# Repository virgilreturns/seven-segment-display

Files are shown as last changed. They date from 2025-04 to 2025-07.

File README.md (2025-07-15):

# seven-segment-display

# Description:
Embedded Microcontroller NUCELO-F401RE Multi-Digit Seven Segment LED Driver using Master-Transmit Only SPI communication with 74HC595 Shift Register.

The objectives of this project are to gain experience with configuring 32-bit microcontrollers, coding in C using the STMCubeIDE, learning how to use Git, using kicad to design footprints and PCBs, 
learning how to get the PCBs manufactured, and learning how to order correct components for cheap. 

This project spanned two months to complete. The code is open-source and free to use. 

# Signal Processing Flow Chart:



# Final Circuit Design



# Final PCB Design



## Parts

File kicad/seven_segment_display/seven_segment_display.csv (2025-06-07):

Reference | Qty | Value | DNP | Exclude from BOM | Exclude from Board | Footprint | Datasheet
DS1 | 1 | LTC-55623G |  |  |  | Library:LTC_5623G-SDIP
R1,R2,R3,R4,R5,R6,R7,R8 | 8 | 660 |  |  |  | Resistor_THT:R_Axial_DIN0207_L6.3mm_D2.5mm_P7.62mm_Horizontal | ~
U1 | 1 | 74AHC595 |  |  |  | Package_DIP:DIP-16_W10.16mm | https://assets.nexperia.com/documents/data-sheet/74AHC_AHCT595.pdf

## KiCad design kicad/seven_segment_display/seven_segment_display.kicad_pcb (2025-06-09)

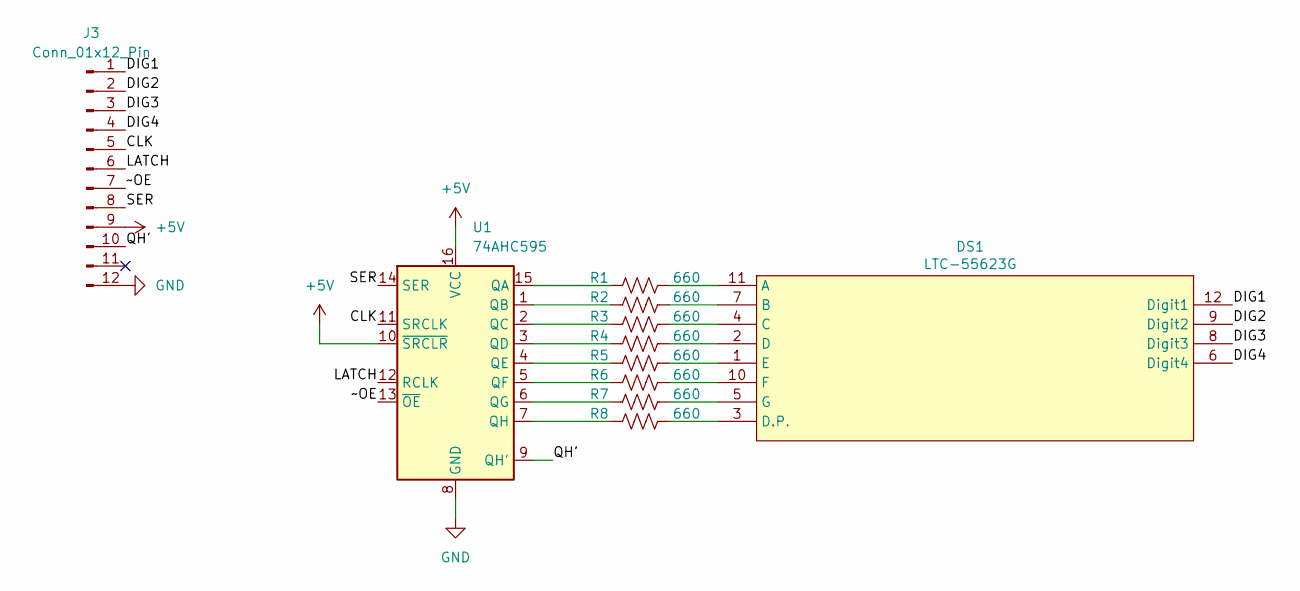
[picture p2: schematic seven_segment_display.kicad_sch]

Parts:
DS1: LTC-55623G; LTC_5623G-SDIP
J3: Conn_01x12_Pin; PinHeader_1x12_P2.54mm_Vertical
R1, R2, R3, R4, R5, R6, R7, R8: 660; R_Axial_DIN0207_L6.3mm_D2.5mm_P7.62mm_Horizontal
U1: 74AHC595; DIP-16_W7.62mm_Socket

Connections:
+5V: J3.9, U1.10 (~SRCLR), U1.16 (VCC)
/CLK: J3.5, U1.11 (SRCLK)
/DIG1: DS1.12 (Digit1), J3.1
/DIG2: DS1.9 (Digit2), J3.2
/DIG3: DS1.8 (Digit3), J3.3
/DIG4: DS1.6 (Digit4), J3.4
/LATCH: J3.6, U1.12 (RCLK)
/QH': J3.10, U1.9 (QH')
/SER: J3.8, U1.14 (SER)
/~OE: J3.7, U1.13 (~OE)
GND: J3.12, U1.8 (GND)
unnamed: DS1.11 (A), R1.2
unnamed: DS1.7 (B), R2.2
unnamed: DS1.4 (C), R3.2
unnamed: DS1.2 (D), R4.2
unnamed: DS1.3 (D.P.), R8.2
unnamed: DS1.1 (E), R5.2
unnamed: DS1.10 (F), R6.2
unnamed: DS1.5 (G), R7.2
unnamed: R1.1, U1.15 (QA)
unnamed: R2.1, U1.1 (QB)
unnamed: R3.1, U1.2 (QC)
unnamed: R4.1, U1.3 (QD)
unnamed: R5.1, U1.4 (QE)
unnamed: R6.1, U1.5 (QF)
unnamed: R7.1, U1.6 (QG)
unnamed: R8.1, U1.7 (QH)

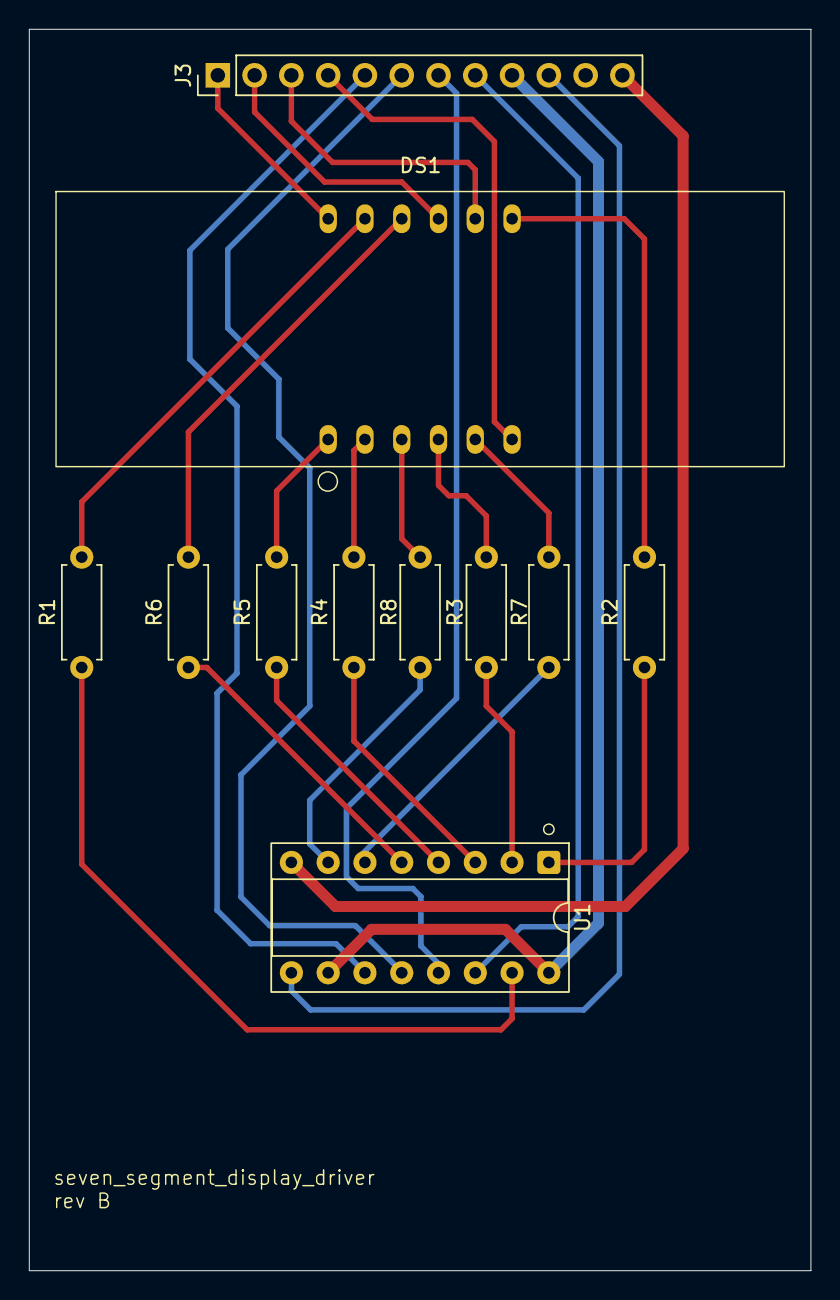
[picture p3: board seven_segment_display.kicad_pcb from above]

Board: 2 copper layers, 54.0 x 85.7 mm, 11 parts (0 on the bottom side), 27 nets.

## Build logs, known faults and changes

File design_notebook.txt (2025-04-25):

 TESTING REQ:
    -INTEGRATED TESTS: 
				     : (COMPLETED 3/20/2025) SHIFT REGISTER + 7 LEDS + BUTTON INTERFACE
					 : (COMPLETED 3/21/2025) SHIFT REGISTER + 7 SEGMENT DISPLAY, (basic test) make sure digital 0 actually is ground
					 : (COMPLETED 3/21/2025) SHIFT REGISTER + 5 DIGIT 7 SEGMENT DISPLAY 
					 : (COMPLETED 3/24/2025) SPI COMMUNICATION + LOGIC ANALYZER 
					 : (COMPLETED 3/25/2025) SPI COMMUNICATION WITH SHIFT REGISTER + 7 SEGMENT DISPLAY (1 digit, 1 character)
					 : (COMPLETED 3/26/2025) CODE ARCHITECTURE FOR MULTIPLEXING DIGITS, ACCURATE DELAYS BETWEEN TRANSMISSION
					 : (COMPLETED 4/24/2025) SPI COMMUNICATION WITH SHIFT REGISTER + 5 DIGIT 7 SEGMENT DISPLAY (use full data buf, see)
					   CHECK GPIO CONTROL PINS, DIGITAL SELECT, LATCH, TIMERS 1,2 requires debugging
					 : (COMPLETED 3/25/2025) CODE ARCHITECTURE FOR BUTTON USER INTERFACE, DEBOUNCE? EXTI CALLBACKS?
					 : (INCOMPLETE) CODE REVISION FOR BUTTON UI IN CONFORMANCE TO NEW STATE MACHINE DESIGN (config & normal)

3/17/2025
  The 74HC595 shift register will be driving up to 7 LEDs. It has a max total output of 70 mA and 35 mA for a single pin.
  With 7 LEDs, the maximum individual output pin current is 6.25 mA which can be achieved with 560 ohm resistor in series with
  the diode.

  TESTING REQ: See how much current provides a satisfactory brightness. Consider a transistor based circuit to drive more
  power for the LEDs, 

  Continue to test shift register with 3mm LEDs for now. Need to fix circuit and use 10k+ pull-up/pulldown resistors for
  SRCLOCK, RCLOCK, and SER. SRCLEAR tied to Vcc and OE tied to GND.  

  TEST REVIEW:  Extreme debounce on all pushbuttons and dip switches :(((
                Overall, shift register seems to work fine.
  
  UPCOMING TASKS:
  - Circuit design for microcontroller to shift register, start firmware for transmitting bits, 
  - Test shift register with 7 segment display, continue using 680 ohm resistors
  - (OPTIONAL) create separate 7 segment display on proto board with resistors and header pins
  - Test SPI communication with shift register and 3mm LEDs
  - Implement SPI communication with shift register and 7 segment display

3/20/2025
  - Successfully tested shift register with 7 segment display. It works as expected.
  - Need to implement SPI communication with the shift register and the 7 segment display.
 
  - further ideas for UI implementation:

 /* ------------------one button config----------------------
	One button is used to cycle through all of the seven_segment characters
	Straight forward and pin resourceful.
*/

 /* ------------------two button config / rotary encoder ----------------------
	Two buttons are used to cycle through all of the seven_segment characters
	Button 1: cycles forward
	Button 2: cycles backwards
	More intuitive than one button, but uses more pins.
*/
 /* ------------------switch encoding config----------------------
	4 dip switches are used to select a specific character to display on the seven_segment.
	Faster to select a specific character, but requires more pins, and a documentation of the encoding.
	Up to number 9 will be in binary, and the other characters can be attained via documentation.
*/

  Keep 8 diode testing setup for testing with SPI functions
  Finished basic seven segment byte transmission code.

  Interested in implementing code for the UI configs

3/21/2025

 Started soldering circuit unto protoboard, probably a bad idea because
 I just had another fantastic idea for an implementation of the project.

 2 button config, one button to cycle through characters, and the other to cycle through the digits.
 This creates a sort of text editor for the seven segment display.

 Other caveats, will need multiplexing with multiple digits, (selecting which VCC to turn on)
 While I only really want no more than 4 digits, I can use a timer to "play" the digits, and shift
 the data through the display. I.E. with 4 digits, I can display a 20 character string by shifting the characters through an array,
 then displaying the array on the 4 digits.

 I can have a timer between configuration and "play" mode, hence if there is no configuration for a certain amount of time, the display will
 start playing the string.

 The first button press of either configuration button will start the configuration mode, and then they will
 function as normal. The display will default to play mode after a certain amount of time of inactivity.

 Other features: A dip switch -> change how many digits are shifted at a time, FULL DISPLAY or BYTE-WISE shifting.
				 -> how big the string can be

 TESTING: Using Analog Discovery 3 (AD3) to read button bounce signal, familizarize with oscilloscope

 Completed:
	-refactored code to support multiple digit display
	-default data will be "Hello"
 
 3/24/2025

	Completed testing SPI communication with logic analyzer. Tested data buffers: (0xFF, 0x33, 0x88, {ASCII_TO_ENUM("HELLo") })
	
	KEY TAKEAWAYS: increase prescaler to decrease the SPI frequency to ~1 Mhz. APB1 peripheral I believe for SPI2. Sysclk / 16 ~ 1Mhz.
	Sample frequency should be at least 4 times greater than the transmission frequency.

	There is a bug where the logic analyzer can accurate detect the first buffer, but will fall out of alignment. Doesn't start reading
	immediately when the CLK goes high...

	Examining HC595 datasheet, provides timing requirements for pulse width, max CLK speeds...

	TODO: CREATE PULSE FUNCTION, ADJUST CLOCK FREQ, TRANSMISSION SEQUENCE
	      TIMING REQUIREMENTS: max CLK speed at 2.0 V = 5 Mhz, 4.5 V = 25 Mhz. Pulse Duration SRCLR 100 ns at 2V,
	      SWITCHING CHARACTERISTICS (input to output): ~250 ns

 3/25/2025
	
	Completed testing SPI communication with shift register + one digit display. 
	Tested data: (ENUM_0, - ENUM_3, ENUM_H, ENUM_n, ENUM_o)

	KEY TAKEAWAYS: ENUM_SEVSEG_CHAR list is not accurately defined, at least for some of the letters.
				 : SPI Could be faster, but I won't be able to read the logic on the analyzer...
				 : Might increase SPI CLk from 1 Mhz to 5 Mhz (max)
	
			 TODO: TEST/DEBUG ENTIRE REFRESH CYCLE/INTERRUPT CHAIN
4/25/2025

	Completed testing full implementation unit test.
	Tested data: {8, r, U, H}, {t, r, o , y}, {H, o, L, y}
	
	KEY TAKEAWAYS:	Increased SPI transmission speed to max frequency (42 Mhz)
				 :	Superloop/Polling design pattern works beautifully
				 
			 TODO:	FINISH SOLDERING PROTO-BOARDS, RESEARCH ENCLOSURE IDEAS
			 	 :	BRAINSTORM FULL HARDWARE IMPLEMENTATION DESIGN

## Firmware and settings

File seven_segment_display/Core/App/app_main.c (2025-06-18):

/*
 * app_main.c
 *
 *  Created on: Apr 16, 2025
 *      Author: virgilreturns
 */

#include "seven_segment_driver.h"
#include "main.h"
#include <stdbool.h>




/* |||||||||||||||||||||  DECLARATIONS  ||||||||||||||||||||||||| */

typedef struct {
	GPIO_TypeDef* port;
	uint16_t pin;
}GPIO_PIN_TypeDef;

extern SPI_HandleTypeDef hspi2;
extern TIM_HandleTypeDef htim3;

SEVSEG_DISPLAY_TypeDef sevseg;

volatile int UI_CURSOR_PRESSED = 0;
volatile int UI_COUNTUP_PRESSED = 0;
volatile int UI_COUNTDOWN_PRESSED = 0;
volatile int TIM2_UP = 0;
volatile int TIM3_UP = false;
volatile int TIM3_CYCLE = 0;
volatile int temp_state = 0;


volatile enum ENUM_SEVSEG_DIGIT cursor_selection = ENUM_SEVSEG_DIGIT_0;
GPIO_PIN_TypeDef DIGIT_SEL_PINS_ARRAY[8];

static void SEVSEG_Init();


/* |||||||||||||||||||||  MAIN  ||||||||||||||||||||||||| */

int app_main(){

	// this is used in sevseg_init

	uint8_t myDataa[4] = {
			ENUM_SEVSEG_CHAR_A,
			ENUM_SEVSEG_CHAR_n,
			ENUM_SEVSEG_CHAR_d,
			ENUM_SEVSEG_CHAR_E,
	};

	uint8_t myDataa2[4] = {
				ENUM_SEVSEG_CHAR_r,
				ENUM_SEVSEG_CHAR_5,
				ENUM_SEVSEG_CHAR_o,
				ENUM_SEVSEG_CHAR_n,
		};


	SEVSEG_Init(myDataa);
	SEVSEG_StoreDataWindow(&sevseg, myDataa); // will store the first 4 of data buffer myDataa
											  // after, only called with sevesg.data_window as 2nd arg

	HAL_TIM_Base_Start_IT(&htim3);

/* |||||||||||||||||||||  LOOP  ||||||||||||||||||||||||| */

	while(1) {

		/* Task 0: Forced State Reconcilation */
		/* if (sevseg.state == SEVSEG_STATE_SCROLLING){ // set to scrolling at sevseg_init() simple solutions:
													 //	implement user controlled play button
													 // cursor button puts into edit mode, must go through all
													 // digit options to return to play mode !!

			TIM3->CR1 |= TIM_CR1_CEN; // 	constantly setting this bit
		}

		*/

		/* Task 1: Polling and Processing */


		/* if (UI_CURSOR_PRESSED) {
			UI_CURSOR_PRESSED = false; //acknowledge

			if (sevseg.state == SEVSEG_STATE_EDITING){ // if already in edit mode, increment digit selection

				if (cursor_selection == ( SEVSEG_QTY_DIGITS - 1)){ // return to scroll state if pressed on the last digit
					sevseg.state = SEVSEG_STATE_SCROLLING; }

				else {cursor_selection++;} // increment cursor

				TIM2->CR1 |= TIM_CR1_CEN; // enable debounce timer
				}

			else { // entering edit state
				sevseg.state = SEVSEG_STATE_EDITING;
				cursor_selection = 0;
			}

		}

		if (UI_COUNTUP_PRESSED){
			UI_COUNTUP_PRESSED = false;

			temp = sevseg.digit_select[cursor_selection].current_char_index;
			if (temp == ENUM_SEVSEG_CHAR_Blank) temp = ENUM_SEVSEG_CHAR_0;
			else temp++;
			sevseg.digit_select[cursor_selection].current_char_index = temp;

			TIM2->CR1 |= TIM_CR1_CEN; // enable debounce timer

		}

		if (UI_COUNTDOWN_PRESSED)	{
			UI_COUNTUP_PRESSED = false;
			temp = sevseg.digit_select[cursor_selection].current_char_index;
			if (temp == ENUM_SEVSEG_CHAR_0) temp = ENUM_SEVSEG_CHAR_Blank;
			else temp--;
			sevseg.digit_select[cursor_selection].current_char_index = temp;

			TIM2->CR1 |= TIM_CR1_CEN;// enable debounce timer
		}

		*/

		/* Task 1.5: Alternating Text */

		 if (TIM3_UP) {
			TIM3_UP = false; // acknowledge

			if (temp_state == 0){
			SEVSEG_StoreDataWindow(&sevseg, myDataa2);
			temp_state = 1;
		 } else {
			 SEVSEG_StoreDataWindow(&sevseg, myDataa);
			 temp_state = 0;
		 }
		 } // end TIM3_UP

		/* Task 2: Render Display */

		HAL_SPI_Transmit(&hspi2, &SEVSEG_CHAR_ARRAY[sevseg.digit_select[sevseg.refresh_target].current_char_index] , 1, 100);
		HAL_GPIO_WritePin(SPI_LATCH_GPIO_Port, SPI_LATCH_Pin, GPIO_PIN_SET);
		HAL_GPIO_WritePin(SPI_LATCH_GPIO_Port, SPI_LATCH_Pin, GPIO_PIN_RESET);

		HAL_GPIO_WritePin(DIGIT_SEL_PINS_ARRAY[sevseg.refresh_target].port,
						  DIGIT_SEL_PINS_ARRAY[sevseg.refresh_target].pin, GPIO_PIN_SET);
		HAL_Delay(1);

		// consider sandwiching processing task during this delay(2) for optmization

		HAL_GPIO_WritePin(DIGIT_SEL_PINS_ARRAY[sevseg.refresh_target].port,
						  DIGIT_SEL_PINS_ARRAY[sevseg.refresh_target].pin, GPIO_PIN_RESET);

		if (sevseg.refresh_target == SEVSEG_QTY_DIGITS - 1) {
			sevseg.refresh_target = ENUM_SEVSEG_DIGIT_0;
		}
		else {
		sevseg.refresh_target += 1;
		}

	} //end while

} //end app_main


/* |||||||||||||||||||||  DEFINITIONS  ||||||||||||||||||||||||| */

static void SEVSEG_Init(uint8_t data_buf[]){

	for (int i = 0; i<SEVSEG_DATA_BUF_SIZE; i++) {
		sevseg.data_buf[i] = data_buf[i];
	}

	sevseg.state = SEVSEG_STATE_SCROLLING;

	// contiguous array of GPIO pins, used for multiplexing displays

	DIGIT_SEL_PINS_ARRAY[ENUM_SEVSEG_DIGIT_0].port = DIGIT_SEL_0_GPIO_Port;
	DIGIT_SEL_PINS_ARRAY[ENUM_SEVSEG_DIGIT_0].pin = DIGIT_SEL_0_Pin;
	DIGIT_SEL_PINS_ARRAY[ENUM_SEVSEG_DIGIT_1].port = DIGIT_SEL_1_GPIO_Port;
	DIGIT_SEL_PINS_ARRAY[ENUM_SEVSEG_DIGIT_1].pin = DIGIT_SEL_1_Pin;
	DIGIT_SEL_PINS_ARRAY[ENUM_SEVSEG_DIGIT_2].port = DIGIT_SEL_2_GPIO_Port;
	DIGIT_SEL_PINS_ARRAY[ENUM_SEVSEG_DIGIT_2].pin = DIGIT_SEL_2_Pin;
	DIGIT_SEL_PINS_ARRAY[ENUM_SEVSEG_DIGIT_3].port = DIGIT_SEL_3_GPIO_Port;
	DIGIT_SEL_PINS_ARRAY[ENUM_SEVSEG_DIGIT_3].pin = DIGIT_SEL_3_Pin;
	DIGIT_SEL_PINS_ARRAY[ENUM_SEVSEG_DIGIT_4].port = DIGIT_SEL_4_GPIO_Port;
	DIGIT_SEL_PINS_ARRAY[ENUM_SEVSEG_DIGIT_4].pin = DIGIT_SEL_4_Pin,
	DIGIT_SEL_PINS_ARRAY[ENUM_SEVSEG_DIGIT_5].port = DIGIT_SEL_1_GPIO_Port;
	DIGIT_SEL_PINS_ARRAY[ENUM_SEVSEG_DIGIT_5].pin = DIGIT_SEL_1_Pin;
	DIGIT_SEL_PINS_ARRAY[ENUM_SEVSEG_DIGIT_6].port = DIGIT_SEL_2_GPIO_Port;
	DIGIT_SEL_PINS_ARRAY[ENUM_SEVSEG_DIGIT_6].pin = DIGIT_SEL_2_Pin,
	DIGIT_SEL_PINS_ARRAY[ENUM_SEVSEG_DIGIT_7].port = DIGIT_SEL_3_GPIO_Port;
	DIGIT_SEL_PINS_ARRAY[ENUM_SEVSEG_DIGIT_7].pin = DIGIT_SEL_3_Pin;


	sevseg.digit_select[0].DS_pin = DIGIT_SEL_0_Pin;
	sevseg.digit_select[0].DS_port = DIGIT_SEL_0_GPIO_Port;
	sevseg.digit_select[0].current_char_index = 0;

	sevseg.digit_select[1].DS_pin = DIGIT_SEL_1_Pin;
	sevseg.digit_select[1].DS_port = DIGIT_SEL_1_GPIO_Port;
	sevseg.digit_select[1].current_char_index = 0;

	sevseg.digit_select[2].DS_pin = DIGIT_SEL_2_Pin;
	sevseg.digit_select[2].DS_port = DIGIT_SEL_2_GPIO_Port;
	sevseg.digit_select[2].current_char_index = 0;

	sevseg.digit_select[3].DS_pin = DIGIT_SEL_3_Pin;
	sevseg.digit_select[3].DS_port = DIGIT_SEL_3_GPIO_Port;
	sevseg.digit_select[3].current_char_index = 0;

	sevseg.refresh_target = ENUM_SEVSEG_DIGIT_0;

}

static const uint16_t UI_ALL_BITS = 7; // 0b0111

void HAL_GPIO_EXTI_Callback(uint16_t pin){
	if (pin == UI_CURSOR_Pin) {
		UI_CURSOR_PRESSED = 1; //invoke
		HAL_GPIO_WritePin(LD2_GPIO_Port, LD2_Pin, GPIO_PIN_SET);
		EXTI->EMR &=~ UI_ALL_BITS; // disable exti lines 0:2
	} else if (pin == UI_COUNTDOWN_Pin) {
		UI_COUNTDOWN_PRESSED = 1;
		HAL_GPIO_WritePin(LD2_GPIO_Port, LD2_Pin, GPIO_PIN_SET);
		EXTI->EMR &=~ UI_ALL_BITS;
	} else if (pin == UI_COUNTUP_Pin) {
		UI_COUNTUP_PRESSED = 1;
		HAL_GPIO_WritePin(LD2_GPIO_Port, LD2_Pin, GPIO_PIN_SET);
		EXTI->EMR &=~ UI_ALL_BITS;
	}
	else {
		__NOP();
	}
}


void HAL_TIM_PeriodElapsedCallback(TIM_HandleTypeDef* htim)
{
  if (htim -> Instance == TIM3){ // scrolling update timer
	  HAL_GPIO_TogglePin(LD2_GPIO_Port, LD2_Pin);
	  TIM3_CYCLE++;

	  if (TIM3_CYCLE > 10) {
		  TIM3_CYCLE = 0;
		  TIM3_UP = true;
	  }

  }
  if (htim -> Instance == TIM2){ //debounce timer 10 kHz -> 50 ms UP One-Pulse-Mode
	  EXTI->EMR |= UI_ALL_BITS;
  }
}

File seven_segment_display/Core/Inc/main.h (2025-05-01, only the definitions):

#define B1_Pin GPIO_PIN_13
#define B1_GPIO_Port GPIOC
#define B1_EXTI_IRQn EXTI15_10_IRQn
#define UI_COUNTDOWN_Pin GPIO_PIN_0
#define UI_COUNTDOWN_GPIO_Port GPIOA
#define UI_COUNTDOWN_EXTI_IRQn EXTI0_IRQn
#define UI_COUNTUP_Pin GPIO_PIN_1
#define UI_COUNTUP_GPIO_Port GPIOA
#define UI_COUNTUP_EXTI_IRQn EXTI1_IRQn
#define UI_CURSOR_Pin GPIO_PIN_2
#define UI_CURSOR_GPIO_Port GPIOA
#define UI_CURSOR_EXTI_IRQn EXTI2_IRQn
#define LD2_Pin GPIO_PIN_5
#define LD2_GPIO_Port GPIOA
#define SPI_RESET_Pin GPIO_PIN_14
#define SPI_RESET_GPIO_Port GPIOB
#define DIGIT_SEL_3_Pin GPIO_PIN_6
#define DIGIT_SEL_3_GPIO_Port GPIOC
#define DIGIT_SEL_1_Pin GPIO_PIN_8
#define DIGIT_SEL_1_GPIO_Port GPIOC
#define DIGIT_SEL_0_Pin GPIO_PIN_9
#define DIGIT_SEL_0_GPIO_Port GPIOC
#define SPI_LATCH_Pin GPIO_PIN_9
#define SPI_LATCH_GPIO_Port GPIOA
#define TMS_Pin GPIO_PIN_13
#define TMS_GPIO_Port GPIOA
#define TCK_Pin GPIO_PIN_14
#define TCK_GPIO_Port GPIOA
#define SWO_Pin GPIO_PIN_3
#define SWO_GPIO_Port GPIOB
#define DIGIT_SEL_2_Pin GPIO_PIN_8
#define DIGIT_SEL_2_GPIO_Port GPIOB
#define DIGIT_SEL_4_Pin GPIO_PIN_9
#define DIGIT_SEL_4_GPIO_Port GPIOB

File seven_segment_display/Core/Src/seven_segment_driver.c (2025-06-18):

/**
 ******************************************************************************
  * @file    seven_segment_driver.c
  * @author  Anderson Nguyen
  * @brief   Seven Segment Display Driver.
  * 
  *          This file provides firmware functions to use SPI with a single
			 SIPO shift register 74HC595 to interface with a Seven Segment 
			 Display of up to 8 digits.
  *          
  *
  ******************************************************************************
  @virgilreturns
  ==============================================================================
                 ##### Seven Segment Display Driver Features #####
  ==============================================================================

  [..]
  This driver comes with customized mode functionality for user interface with 
  a seven segment display. The purpose of this driver is to provide a simple way
  for a user to change values on a seven segment display using only a few discrete
  buttons. This would function as a basic text editor.

  Such UI implementations include:
  (+) One button config, where a single button is used to cycle through
	  the characters on the display; only compatible with a single digit.
  (+) Two button config, where one button is used to increment the character and
	  another to decrement the character.
  (+) Two button config plus, where a single button is used to cycle through
	  the characters and another to cycle through the digits.
  (+) Three button config, where one button is used to increment the character,
	  another to decrement the character, and a third to cycle digits.
  (+) Rotary Encoder config, where a rotary encoder can cycle digits or character, 
	  and a switch multiplexes which to cycle through
  
					   ##### How to use this driver #####
  ==============================================================================

	(#) define SEVSEG_QTY_DIGITS to the number of digits on the display

	(#) Create a SEVSEG_DISPLAY_TypeDef object and initialize it with the SPI handler
		and the GPIO digit select pins for each digit.

	(#) Initialize buttons/switches and other UI elements for external interrupts

	(#) create a data buffer of ENUM_SEVSEG_CHAR and initialize it with ENUM_SEVSEG_CHAR
		characters that you wish to display.

	(#) Call SEVSEG_StoreDataBuf() to store the data buffer in the display struct





  @endvirgilreturns
  ******************************************************************************
  */

#include "seven_segment_driver.h"


const uint16_t INDEX_FROM_ENUM[0x102] = {
    [ENUM_SEVSEG_CHAR_0] = 0,
    [ENUM_SEVSEG_CHAR_1] = 1,
    [ENUM_SEVSEG_CHAR_2] = 2,
    [ENUM_SEVSEG_CHAR_3] = 3,
    [ENUM_SEVSEG_CHAR_4] = 4,
    [ENUM_SEVSEG_CHAR_5] = 5,
    [ENUM_SEVSEG_CHAR_6] = 6,
    [ENUM_SEVSEG_CHAR_7] = 7,
    [ENUM_SEVSEG_CHAR_8] = 8,
    [ENUM_SEVSEG_CHAR_9] = 9,
    [ENUM_SEVSEG_CHAR_A] = 10,
    [ENUM_SEVSEG_CHAR_B] = 11,
    [ENUM_SEVSEG_CHAR_C] = 12,
    [ENUM_SEVSEG_CHAR_d] = 13,
    [ENUM_SEVSEG_CHAR_E] = 14,
    [ENUM_SEVSEG_CHAR_F] = 15,
    [ENUM_SEVSEG_CHAR_h] = 16,
    [ENUM_SEVSEG_CHAR_H] = 17,
    [ENUM_SEVSEG_CHAR_L] = 18,
    [ENUM_SEVSEG_CHAR_n] = 19,
    [ENUM_SEVSEG_CHAR_o] = 20,
    [ENUM_SEVSEG_CHAR_P] = 21,
    [ENUM_SEVSEG_CHAR_r] = 22,
    [ENUM_SEVSEG_CHAR_t] = 23,
    [ENUM_SEVSEG_CHAR_U] = 24,
    [ENUM_SEVSEG_CHAR_Y] = 25,
    [ENUM_SEVSEG_CHAR_Dash] = 26,
    [ENUM_SEVSEG_CHAR_Blank] = 27
};

 enum ENUM_SEVSEG_CHAR SEVSEG_CHAR_ARRAY[] = {
    ENUM_SEVSEG_CHAR_0,
    ENUM_SEVSEG_CHAR_1,
    ENUM_SEVSEG_CHAR_2,
    ENUM_SEVSEG_CHAR_3,
    ENUM_SEVSEG_CHAR_4,
    ENUM_SEVSEG_CHAR_5,
    ENUM_SEVSEG_CHAR_6,
    ENUM_SEVSEG_CHAR_7,
    ENUM_SEVSEG_CHAR_8,
    ENUM_SEVSEG_CHAR_9,
    ENUM_SEVSEG_CHAR_A,
    ENUM_SEVSEG_CHAR_B,
    ENUM_SEVSEG_CHAR_C,
    ENUM_SEVSEG_CHAR_d,
    ENUM_SEVSEG_CHAR_E,
    ENUM_SEVSEG_CHAR_F,
    ENUM_SEVSEG_CHAR_h,
    ENUM_SEVSEG_CHAR_H,
    ENUM_SEVSEG_CHAR_L,
    ENUM_SEVSEG_CHAR_n,
    ENUM_SEVSEG_CHAR_o,
    ENUM_SEVSEG_CHAR_P,
    ENUM_SEVSEG_CHAR_r,
    ENUM_SEVSEG_CHAR_t,
    ENUM_SEVSEG_CHAR_U,
    ENUM_SEVSEG_CHAR_Y,
    ENUM_SEVSEG_CHAR_Dash,
    ENUM_SEVSEG_CHAR_Blank
    };

 const enum ENUM_SEVSEG_CHAR ASCII_to_SEVSEG_CHAR[255] = {
     ['0'] = ENUM_SEVSEG_CHAR_0,
     ['1'] = ENUM_SEVSEG_CHAR_1,
     ['2'] = ENUM_SEVSEG_CHAR_2,
     ['3'] = ENUM_SEVSEG_CHAR_3,
     ['4'] = ENUM_SEVSEG_CHAR_4,
     ['5'] = ENUM_SEVSEG_CHAR_5,
     ['6'] = ENUM_SEVSEG_CHAR_6,
     ['7'] = ENUM_SEVSEG_CHAR_7,
     ['8'] = ENUM_SEVSEG_CHAR_8,
     ['9'] = ENUM_SEVSEG_CHAR_9,
     ['A'] = ENUM_SEVSEG_CHAR_A,
     ['B'] = ENUM_SEVSEG_CHAR_B,
     ['C'] = ENUM_SEVSEG_CHAR_C,
     ['D'] = ENUM_SEVSEG_CHAR_d,
     ['E'] = ENUM_SEVSEG_CHAR_E,
     ['F'] = ENUM_SEVSEG_CHAR_F,
     ['h'] = ENUM_SEVSEG_CHAR_h,
     ['H'] = ENUM_SEVSEG_CHAR_H,
     ['L'] = ENUM_SEVSEG_CHAR_L,
     ['n'] = ENUM_SEVSEG_CHAR_n,
     ['o'] = ENUM_SEVSEG_CHAR_o,
     ['P'] = ENUM_SEVSEG_CHAR_P,
     ['r'] = ENUM_SEVSEG_CHAR_r,
     ['t'] = ENUM_SEVSEG_CHAR_t,
     ['U'] = ENUM_SEVSEG_CHAR_U,
     ['Y'] = ENUM_SEVSEG_CHAR_Y,
     ['-'] = ENUM_SEVSEG_CHAR_Dash,
     [' '] = ENUM_SEVSEG_CHAR_Blank,
 };

//stores look-up indexes (user-defined-pointers) into each DIGIT in sevseg.digits_select[DIGIT]
void SEVSEG_StoreDataWindow(SEVSEG_DISPLAY_TypeDef* sevseg, enum ENUM_SEVSEG_CHAR data[]) {
	for (int i = 0; i < SEVSEG_QTY_DIGITS; i++) {
		sevseg->digit_select[i].current_char_index = INDEX_FROM_ENUM[data[i]];
	}
};

enum ENUM_SEVSEG_CHAR SEVSEG_ReadDigitData(SEVSEG_DISPLAY_TypeDef *sevseg, enum ENUM_SEVSEG_DIGIT target) {
	return SEVSEG_CHAR_ARRAY[sevseg->digit_select[target].current_char_index];
}

HAL_StatusTypeDef SEVSEG_DigitTx(SEVSEG_DISPLAY_TypeDef* sevseg) {
	enum ENUM_SEVSEG_CHAR temp = SEVSEG_CHAR_ARRAY[(sevseg->digit_select[sevseg->refresh_target].current_char_index)];
	// write data through MOSI (SPI2 handler)
    HAL_StatusTypeDef success = HAL_SPI_Transmit(sevseg->spi_handler, &(SEVSEG_CHAR_ARRAY[(sevseg->digit_select[sevseg->refresh_target].current_char_index)]), 1, 1000); //send data through MOSI pin
	if (success != HAL_OK) return success; //if error, return error code

	return success;
};

void SEVSEG_ScrollDataWindow(SEVSEG_DISPLAY_TypeDef* sevseg){

	for (int i = 0; i < SEVSEG_QTY_DIGITS-1; i++){
		sevseg->data_window[i] = sevseg->data_buf[(sevseg->scroll_head + i) % SEVSEG_DATA_BUF_SIZE];
	}

	if (sevseg->scroll_head == SEVSEG_DATA_BUF_SIZE - 1) { // at the end of the data buffer
		sevseg->scroll_head = 0;
	} else;
	sevseg->scroll_head++;

}

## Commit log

2025-04-21 debounce system implemented using interrupts processed in task 1 by main
2025-04-24 Fixed re-declaring GPIO_PIN_ARRAY, successful test of multiplexing
    [app_main.c, main.h]
2025-05-01 Exti Line works, tested with onboard led
2025-05-01 timer3 isr running
2025-05-15 bug fixes in exti, hopefully finished UI implementation, requires integrated testing
    [app_main.c, seven_segment_display.ioc]
2025-06-07 added kicad
    [seven_segment_display.csv, seven_segment_display.kicad_pcb, seven_segment_display.kicad_sch]
2025-06-09 final pcb design completed
    [seven_segment_display.kicad_pcb, seven_segment_display.kicad_sch]

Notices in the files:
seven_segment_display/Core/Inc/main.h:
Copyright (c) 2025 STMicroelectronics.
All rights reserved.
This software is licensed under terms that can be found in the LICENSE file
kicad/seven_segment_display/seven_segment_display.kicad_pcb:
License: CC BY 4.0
